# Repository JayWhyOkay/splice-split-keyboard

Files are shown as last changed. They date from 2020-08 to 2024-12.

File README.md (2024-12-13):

# Splice - A Split Alice

*Splice* is a split keyboard in the Alice layout. 

The goal is to design a board suited for myself as there are no boards designed quite like the Alice. Most split boards are generally based on an ortholinear layout, something that I personally canntot get used to. 

The keyboard is based off [the Sofle Keyboard from Josef](https://github.com/josefadamcik/SofleKeyboard), with adjustments made to fit the preferred layout. 

Notes: Revision 1 and 2 PCB uses CFTKB and Sofle footprints, and all credits for footprints used belong to the respective footprint designer. 

## Images

Below are images of renders and prototypes. 

Complete project will come soon. 

Prototype of Revision 1
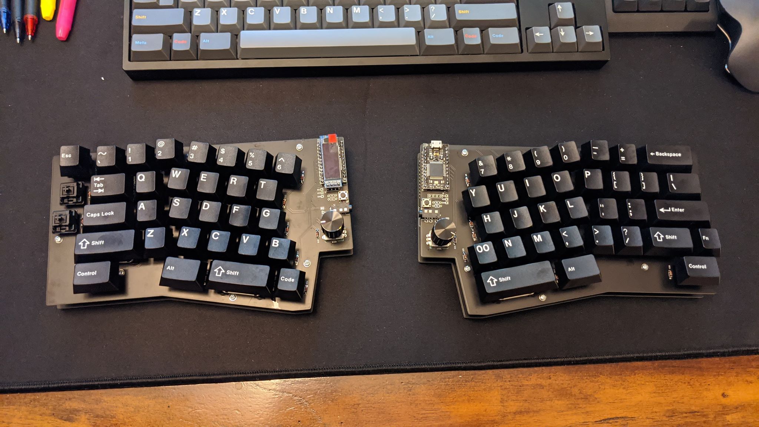
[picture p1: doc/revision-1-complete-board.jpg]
Revision 1 PCB


## Changelist

### Revision 3:
- TBA
- Normal and stepped caps support
- 2U, 2.25U spacebar support on left side
- indicator LEDs?

### Revision 2: 
- Shortened PCB dimensions 
- Relocated TRRS connector to top towards MCU Port
- Readjusted OLED Breakout 
- Added silkscreen logos for the board

## Future Changes and To-Do List
- Refactor schematics to support ai03 footprints
- make an Atmega32u4 version
- 2024: Update to latest QMK version!

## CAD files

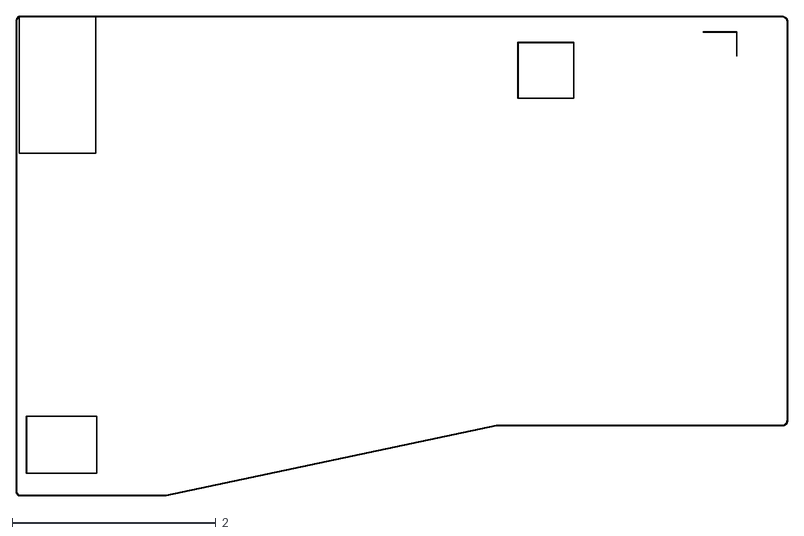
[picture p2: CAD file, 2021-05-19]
pcb-right/right-plate/right-plate.dxf
7.58 x 4.71

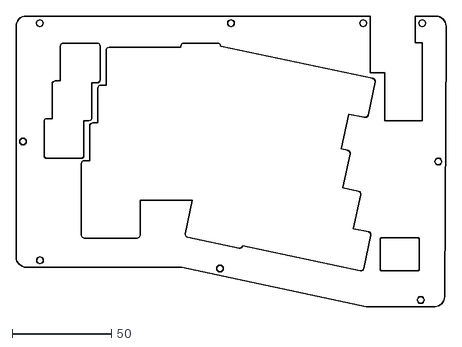
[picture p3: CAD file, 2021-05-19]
acrylic_case_files/Revision 2 Case Files/Left-Upper-Fill-Lower.dxf
216.9 x 146.6

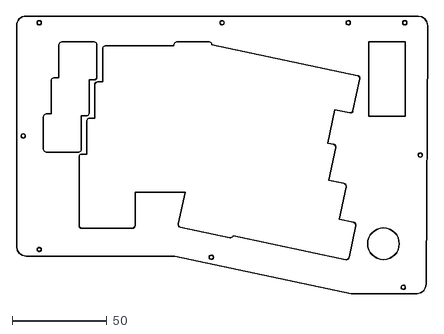
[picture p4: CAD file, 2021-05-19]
acrylic_case_files/Revision 2 Case Files/Left-Top-Layer.dxf
216.9 x 146.6

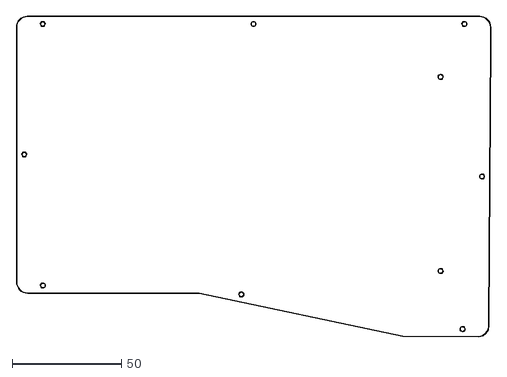
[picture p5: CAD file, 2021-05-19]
acrylic_case_files/Revision 2 Case Files/Bottom-Layer.dxf
216.9 x 146.6

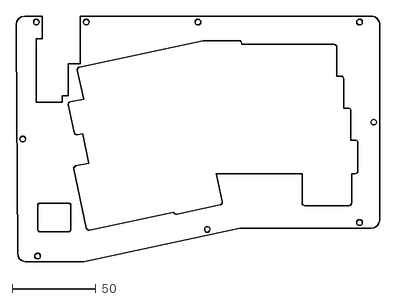
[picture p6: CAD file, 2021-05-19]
acrylic_case_files/Revision 2 Case Files/Right-Upper-Fill-Lower.dxf
216.9 x 146.6

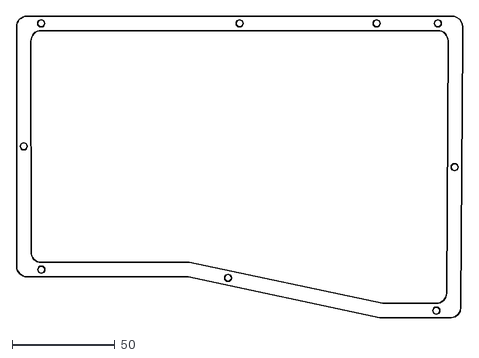
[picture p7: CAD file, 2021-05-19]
acrylic_case_files/Revision 2 Case Files/Lower-Fill-Lower.dxf
216.9 x 146.6

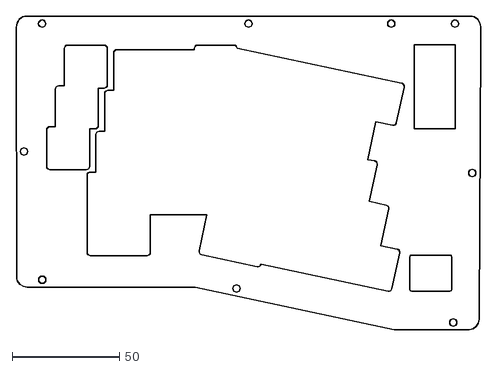
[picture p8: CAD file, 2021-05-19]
acrylic_case_files/Revision 2 Case Files/Left-Upper-Fill-Upper.dxf
216.9 x 146.6

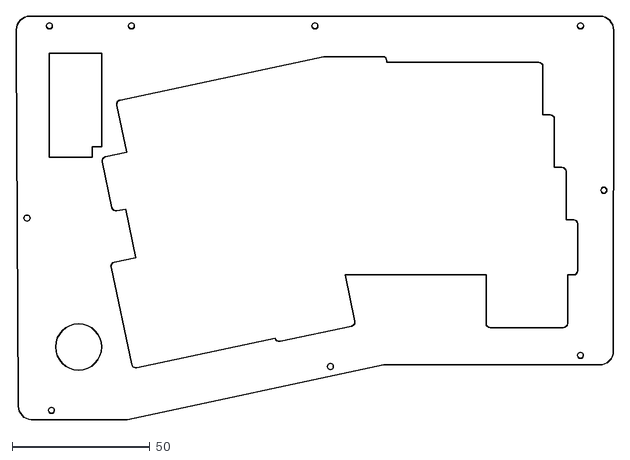
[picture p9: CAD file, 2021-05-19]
acrylic_case_files/Revision 2 Case Files/Right-Top-Layer.dxf
216.9 x 146.6

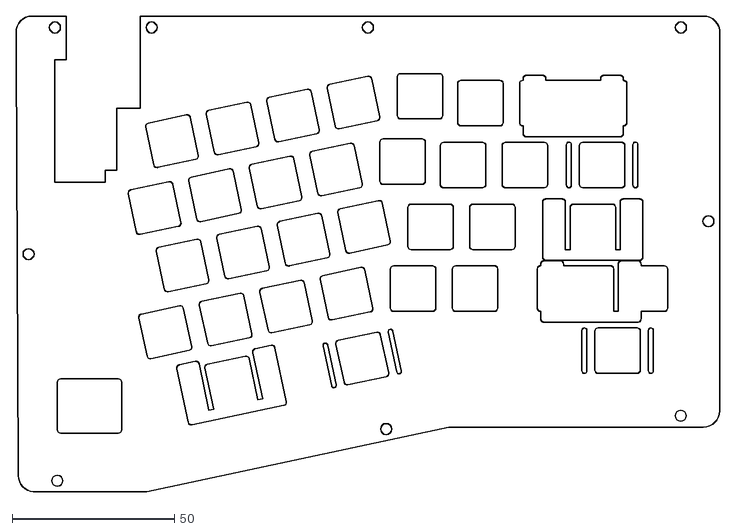
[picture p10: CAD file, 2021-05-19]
acrylic_case_files/Revision 2 Case Files/Right-Plate.dxf
216.9 x 146.6

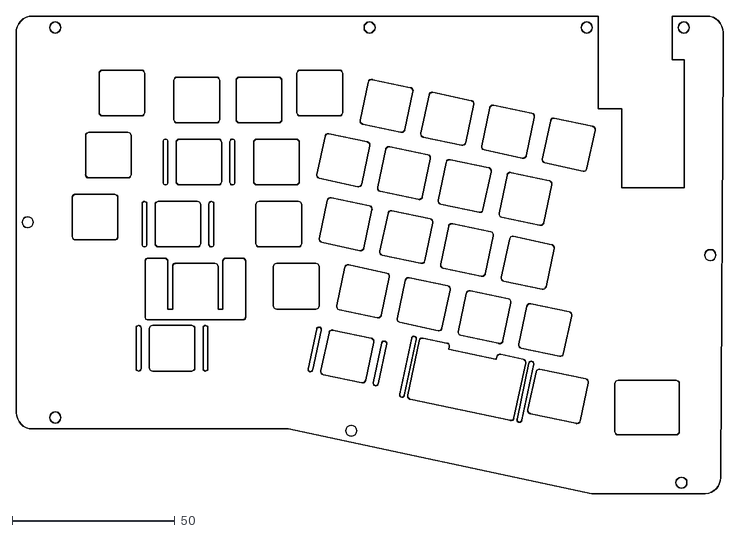
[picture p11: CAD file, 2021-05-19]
acrylic_case_files/Revision 2 Case Files/Left-Plate.dxf
216.9 x 146.6

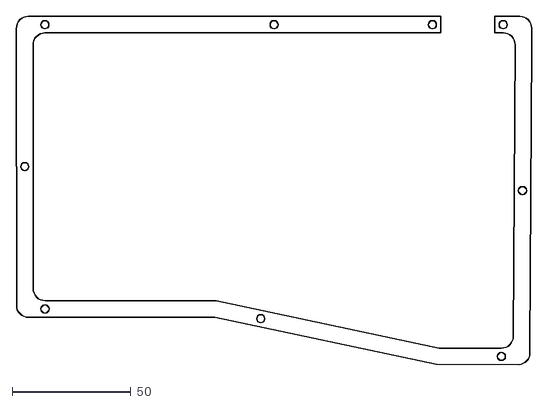
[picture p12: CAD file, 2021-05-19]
acrylic_case_files/Revision 2 Case Files/Lower-Fill-Upper.dxf
216.9 x 146.6

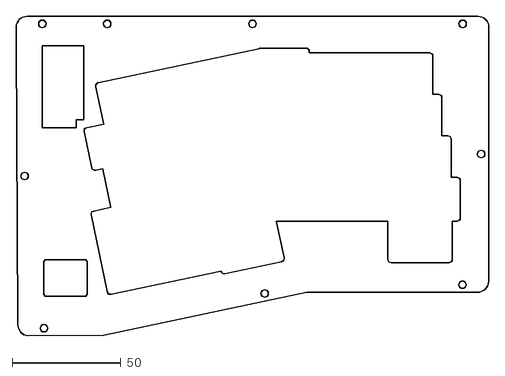
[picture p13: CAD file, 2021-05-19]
acrylic_case_files/Revision 2 Case Files/Right-Upper-Fill-Upper.dxf
216.9 x 146.6

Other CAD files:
acrylic_case_files/Revision 2 Case Files/Acrylic-Foot-3.dxf
acrylic_case_files/Revision 2 Case Files/DWG/__feet_template__.dwg
acrylic_case_files/Revision 2 Case Files/DWG/__left_master_template__.dwg
acrylic_case_files/Revision 2 Case Files/DWG/__right_master_template__.dwg
acrylic_case_files/Revision 2 Case Files/Acrylic-Foot-2.dxf
acrylic_case_files/Revision 2 Case Files/Acrylic-Foot-1.dxf
acrylic_case_files/Revision 1 Case Files/DWG/Bottom-Layer.dwg
acrylic_case_files/Revision 1 Case Files/DWG/Left-Mid-Top-Layer.dwg
acrylic_case_files/Revision 1 Case Files/DWG/Left-Plate.dwg
acrylic_case_files/Revision 1 Case Files/DWG/Left-Top-Layer.dwg
acrylic_case_files/Revision 1 Case Files/DWG/Lower-Fill-1.dwg
acrylic_case_files/Revision 1 Case Files/DWG/Lower-Fill-2.dwg
acrylic_case_files/Revision 1 Case Files/DWG/Right-Mid-Top.dwg
acrylic_case_files/Revision 1 Case Files/DWG/Right-Plate.dwg
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

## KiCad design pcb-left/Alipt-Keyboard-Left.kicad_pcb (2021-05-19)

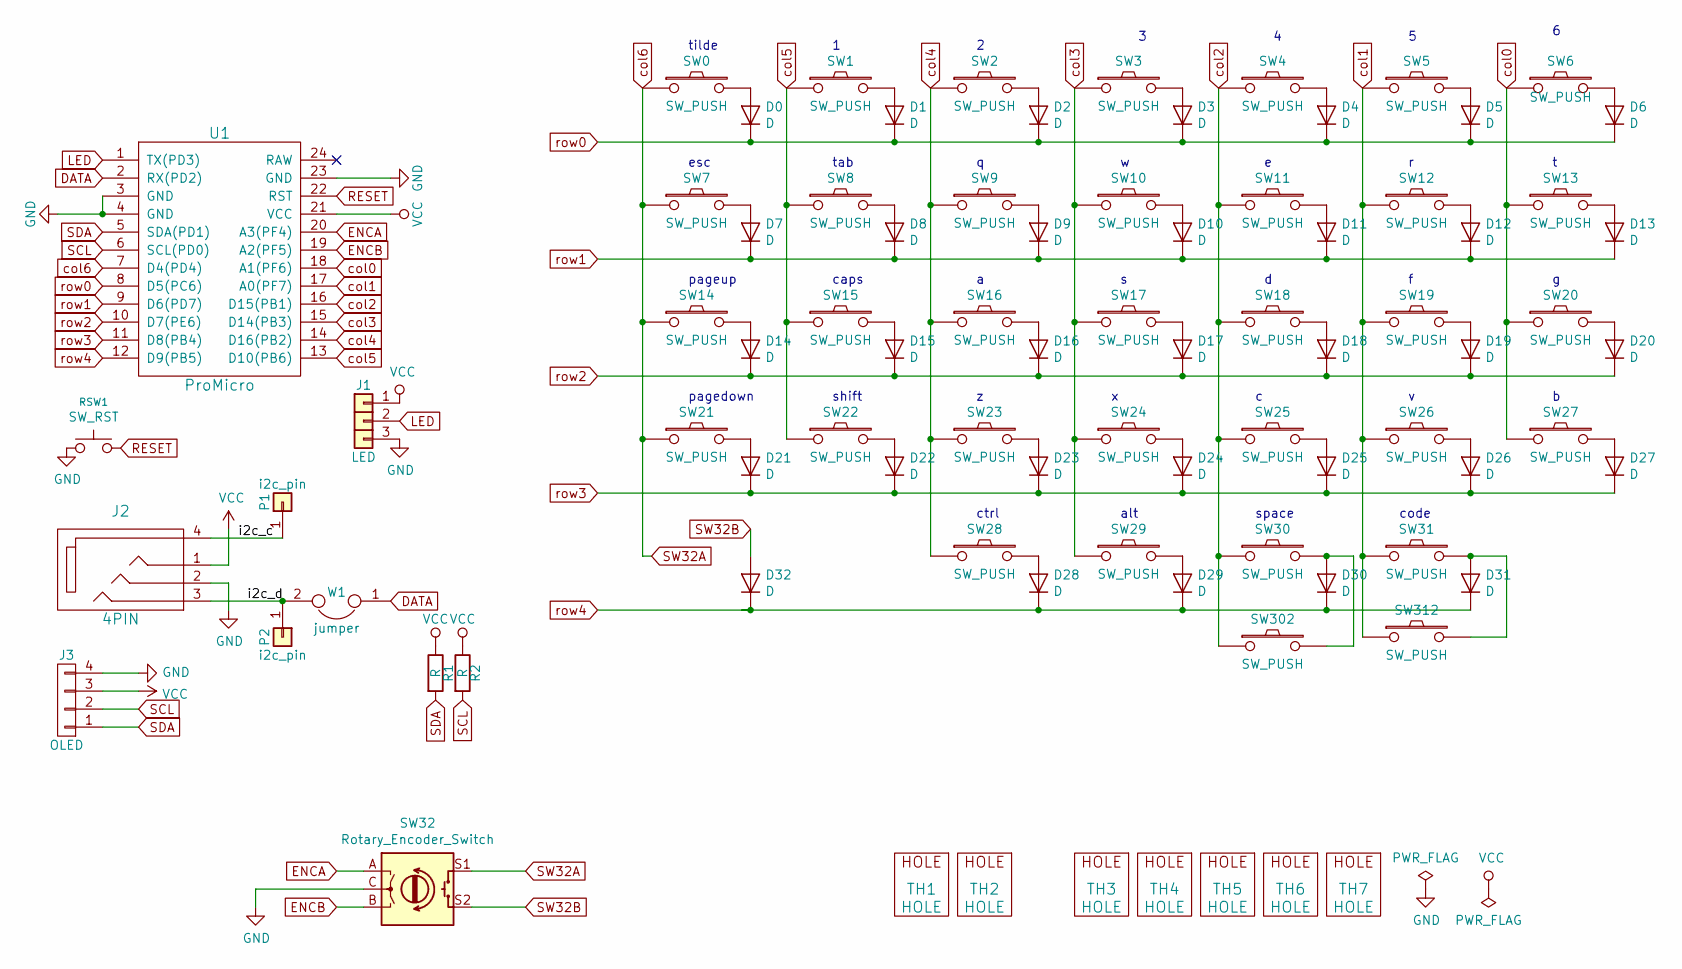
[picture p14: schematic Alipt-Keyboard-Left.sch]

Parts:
D0, D1, D2, D3, D4, D5, D6, D7, D8, D9, D10, D11, D12, D13, D14, D15, D16, D17, D18, D19, D20, D21, D22, D23, D24, D25, D26, D27, D28, D29, D30, D31, D32: D; D_DO-35_SOD27_P5.08mm_Horizontal
J1: LED
J2: 4PIN; MJ-4PP-9
J3: OLED; OLED_4Pin
P1, P2: i2c_pin; 1pin_conn
R1, R2: R; RESISTOR_mini
RSW1: SW_RST; SW_PUSH_6mm
SW0, SW1, SW2, SW3, SW4, SW5, SW6, SW7, SW9, SW10, SW11, SW12, SW13, SW14, SW16, SW17, SW18, SW19, SW20, SW21, SW23, SW24, SW25, SW26, SW27, SW31: SW_PUSH; SW_Cherry_MX1A_1.00u_PCB-NOSCREEN
SW8, SW28, SW29: SW_PUSH; SW_Cherry_MX1A_1.50u_PCBNOSCREEN
SW15: SW_PUSH; SW_Cherry_MX1A_1.75u_PCBNOSCREEN
SW22, SW30: SW_PUSH; SW_Cherry_MX1A_2.25u_PCBNOSCREEN
SW32: Rotary_Encoder_Switch; RotaryEncoder_Alps_EC11E-Switch_Vertical_H20mm-keebio_modif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
SW302: SW_PUSH; SW_Cherry_MX1A_2.00u_PCBNOSCREEN
SW312: SW_PUSH; SW_Cherry_MX1A_1.25u_PCBNOSCREEN
TH1, TH2, TH3, TH4, TH5, TH6, TH7: HOLE; MountingHole_2.2mm_M2_Pad
U1: ProMicro
W1: jumper; jumper_data

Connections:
/i2c_c: J2.4, P1.1
/i2c_d: J2.3, P2.1, W1.2
DATA: U1.2 (RX(PD2)), W1.1
ENCA: SW32.A, U1.20 (A3(PF4))
ENCB: SW32.B, U1.19 (A2(PF5))
GND: J1.3, J2.2, J3.4, RSW1.1, SW32.C, U1.3 (GND), U1.4 (GND), U1.23 (GND)
LED: J1.2, U1.1 (TX(PD3))
unnamed: D0.2 (A), SW0.2
unnamed: D1.2 (A), SW1.2
unnamed: D2.2 (A), SW2.2
unnamed: D3.2 (A), SW3.2
unnamed: D4.2 (A), SW4.2
unnamed: D5.2 (A), SW5.2
unnamed: D6.2 (A), SW6.2
unnamed: D7.2 (A), SW7.2
unnamed: D8.2 (A), SW8.2
unnamed: D9.2 (A), SW9.2
unnamed: D10.2 (A), SW10.2
unnamed: D11.2 (A), SW11.2
unnamed: D12.2 (A), SW12.2
unnamed: D13.2 (A), SW13.2
unnamed: D14.2 (A), SW14.2
unnamed: D15.2 (A), SW15.2
unnamed: D16.2 (A), SW16.2
unnamed: D17.2 (A), SW17.2
unnamed: D18.2 (A), SW18.2
unnamed: D19.2 (A), SW19.2
unnamed: D20.2 (A), SW20.2
unnamed: D21.2 (A), SW21.2
unnamed: D22.2 (A), SW22.2
unnamed: D23.2 (A), SW23.2
unnamed: D24.2 (A), SW24.2
unnamed: D25.2 (A), SW25.2
unnamed: D26.2 (A), SW26.2
unnamed: D27.2 (A), SW27.2
unnamed: D28.2 (A), SW28.2
unnamed: D29.2 (A), SW29.2
unnamed: D30.2 (A), SW30.2, SW302.2
unnamed: D31.2 (A), SW31.2, SW312.2
RESET: RSW1.2, U1.22 (RST)
SCL: J3.2, R2.2, U1.6 (SCL(PD0))
SDA: J3.1, R1.2, U1.5 (SDA(PD1))
SW32A: SW0.1, SW7.1, SW14.1, SW21.1, SW32.S1, U1.7 (D4(PD4))
SW32B: D32.2 (A), SW32.S2
VCC: J1.1, J2.1, J3.3, R1.1, R2.1, U1.21 (VCC)
col0: SW6.1, SW13.1, SW20.1, SW27.1, U1.18 (A1(PF6))
col1: SW5.1, SW12.1, SW19.1, SW26.1, SW31.1, SW312.1, U1.17 (A0(PF7))
col2: SW4.1, SW11.1, SW18.1, SW25.1, SW30.1, SW302.1, U1.16 (D15(PB1))
col3: SW3.1, SW10.1, SW17.1, SW24.1, SW29.1, U1.15 (D14(PB3))
col4: SW2.1, SW9.1, SW16.1, SW23.1, SW28.1, U1.14 (D16(PB2))
col5: SW1.1, SW8.1, SW15.1, SW22.1, U1.13 (D10(PB6))
row0: D0.1 (K), D1.1 (K), D2.1 (K), D3.1 (K), D4.1 (K), D5.1 (K), D6.1 (K), U1.8 (D5(PC6))
row1: D7.1 (K), D8.1 (K), D9.1 (K), D10.1 (K), D11.1 (K), D12.1 (K), D13.1 (K), U1.9 (D6(PD7))
row2: D14.1 (K), D15.1 (K), D16.1 (K), D17.1 (K), D18.1 (K), D19.1 (K), D20.1 (K), U1.10 (D7(PE6))
row3: D21.1 (K), D22.1 (K), D23.1 (K), D24.1 (K), D25.1 (K), D26.1 (K), D27.1 (K), U1.11 (D8(PB4))
row4: D28.1 (K), D29.1 (K), D30.1 (K), D31.1 (K), D32.1 (K), U1.12 (D9(PB5))

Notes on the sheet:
tab
caps
shift
code
space
alt
ctrl
tilde
esc
pageup
pagedown

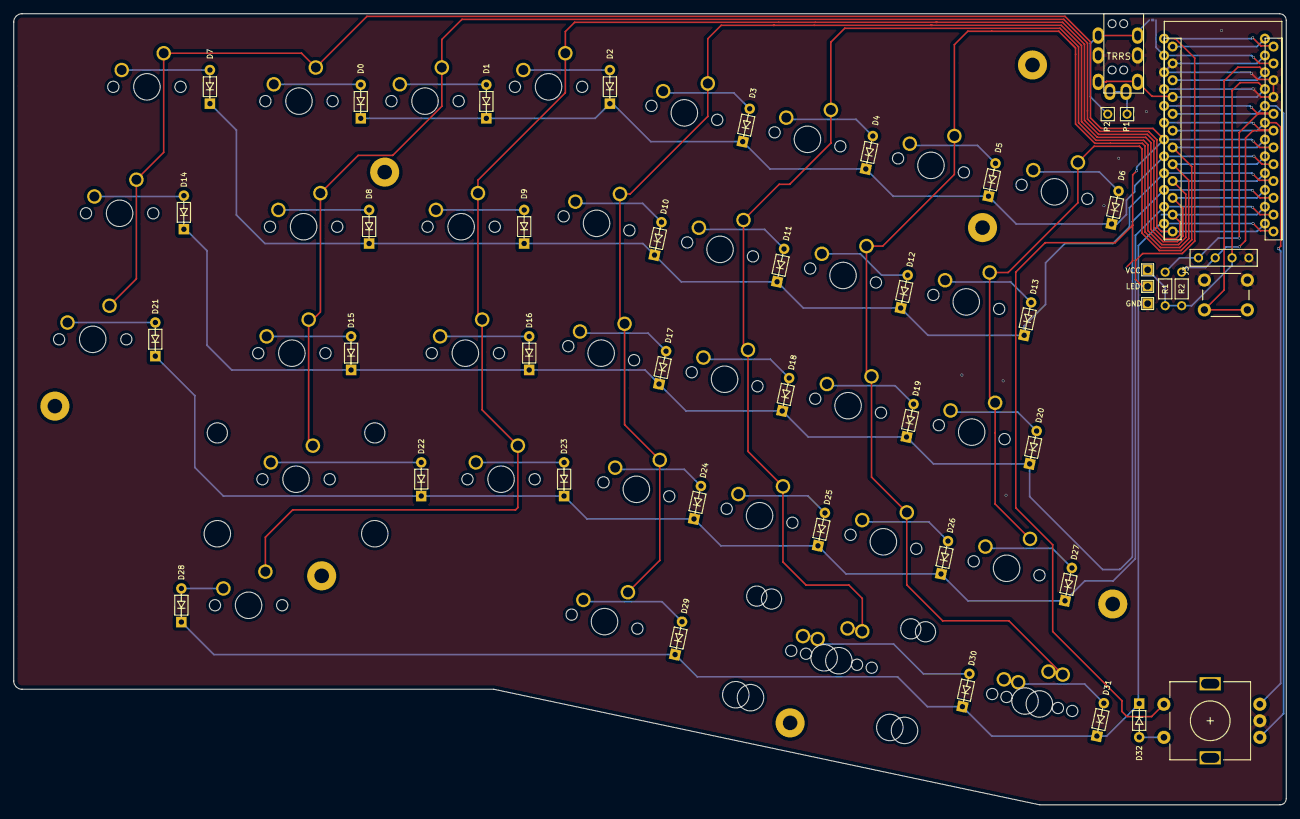
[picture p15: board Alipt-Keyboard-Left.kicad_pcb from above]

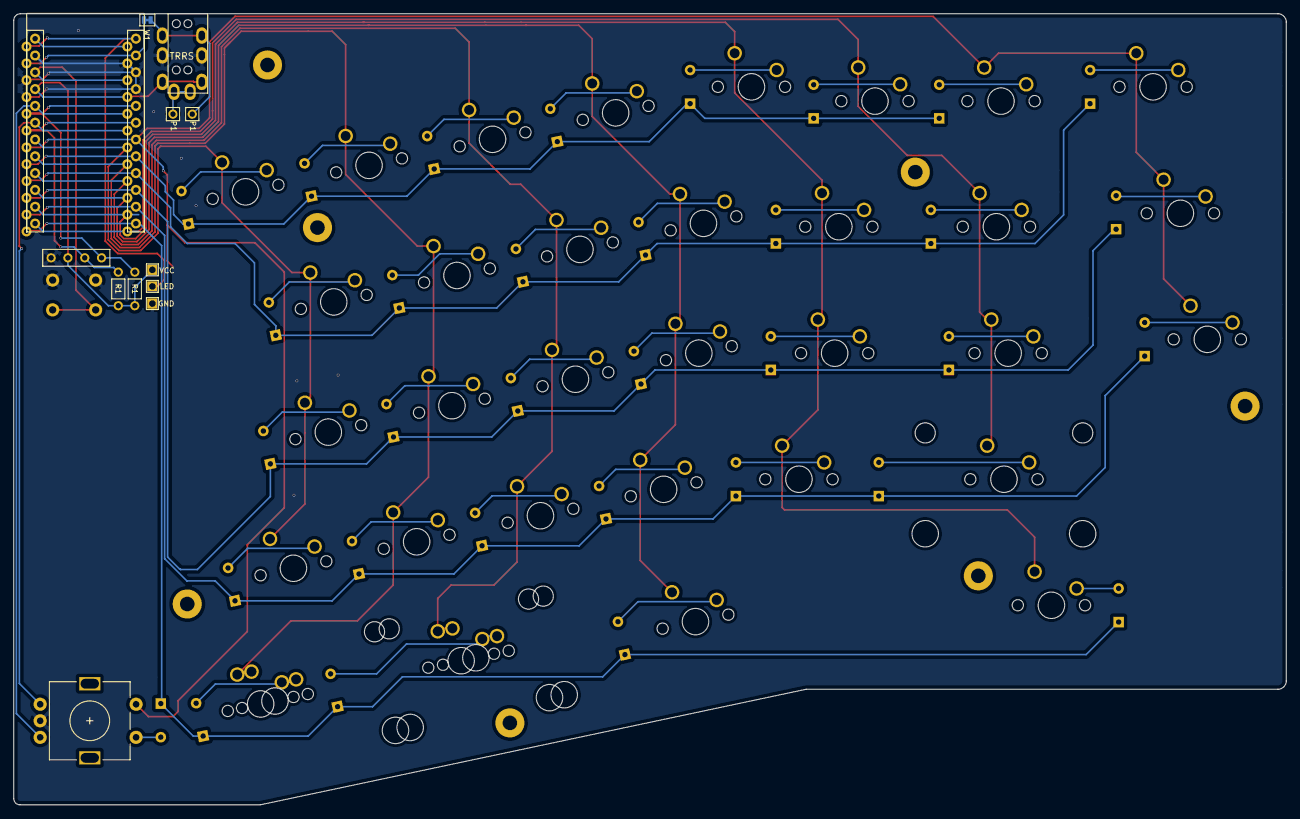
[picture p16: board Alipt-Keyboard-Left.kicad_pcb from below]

Board: 2 copper layers, 192.3 x 119.6 mm, 85 parts (2 on the bottom side), 56 nets.

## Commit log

2020-07-22 Layout and beginning of wire traces for left side
    [Alipt-Keyboard-Left.kicad_pcb, Alipt-Keyboard-Left.sch, Drawing1.dxf]
2020-07-22 Layout started for right side
    [Alipt-Keyboard-Right.kicad_pcb, Alipt-Keyboard-Right.sch, right layout.dxf]
2020-08-20 revision 1 complete pcbs
    [Alipt-Keyboard-Left-B_Cu.gbl, Alipt-Keyboard-Left-B_Mask.gbs, Alipt-Keyboard-Left-B_Paste.gbp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]
2020-09-17 Near finalization of revision 1
    [Bottom-Layer.dwg, Left-Mid-Top-Layer.dwg, Left-Plate-no-flex.dxf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]
